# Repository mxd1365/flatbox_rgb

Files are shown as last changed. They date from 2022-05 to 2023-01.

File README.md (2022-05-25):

# Flatbox: Low profile hitbox-layout fightstick

This repository contains 3D-printable models, PCB design files and code needed to make an arcade controller that looks like this:

Assembled Flatbox

There are four major versions of the Flatbox. They all use Kailh low profile (choc v1) mechanical keyboard switches. The table below lists their main features. See the README for each version for details on how to make them.

version | [rev1.1](hardware-rev1.1) | [rev2](hardware-rev2) | [rev3](hardware-rev3) | [rev4](hardware-rev4) | [rev4_rgb](hardware-rev4_rgb)
------- | ------------------------- | --------------------- | --------------------- | --------------------- | ---------------------
case dimensions | 218x128x10mm | 218x130x10mm | 218x130x10mm | 218x130x10mm | 218x130x10mm
compatibility (using provided firmware) | PC, PS3 | PC, PS3 | PC, PS3, PS4 | PC, PS3 | PC, PS3
add-on board | Arduino Pro Micro | - | [Brook PS3/PS4](https://www.brookaccessory.com/detail/58690501/) | - | -
onboard chip | - | ATmega32U4 | - | RP2040 | RP2040
port | micro USB | USB-C | USB-C | USB-C | USB-C
SMT assembly required | no | yes | yes | yes | yes
firmware | [ATmega32U4](firmware-atmega32u4) | [ATmega32U4](firmware-atmega32u4) | [Brook](https://www.brookaccessory.com/download/PS3/) | [RP2040](firmware-rp2040) | [RP2040_RGB](firmware-rp2040_rgb)

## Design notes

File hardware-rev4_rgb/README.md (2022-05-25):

# Flatbox rev4

This is rev4 of the Flatbox with RBG added for each button. In this version the PCB includes a microcontroller and USB port. Everything is built in, you only have to add the switches (and flash the firmware).

To make one you will need:

* [3D printed case parts](3d-printed-case) - top and bottom
* [the PCB](pcb)
* 12x Kailh low profile (choc v1) switches of your choice
* (optionally) 12x Kailh low profile hotswap sockets
* [3D printed buttoncaps](../3d-printed-buttoncaps)
* 6x 6x6x5mm tact switches
* 7x 3x10mm wood screws
* some kind of rubber feet or non-slip padding for the bottom
* a soldering iron

I printed the case at 0.20mm layer height. The top part should be printed upside-down, the bottom part should be printed as-is. They don't require supports.

I used [JLCPCB](https://jlcpcb.com/) to make the PCB and assemble the SMD parts. The [included files](pcb) can be used with JLCPCB directly. If you want to use some other service, check the file formats that they expect. When ordering from JLCPCB, upload the Gerber zip, leave all the settings at default (you can choose the PCB color), then select "SMT Assembly" and upload the BOM and CPL files. PCB thickness should be 1.6mm.

The PCB you get from JLCPCB will look like this:

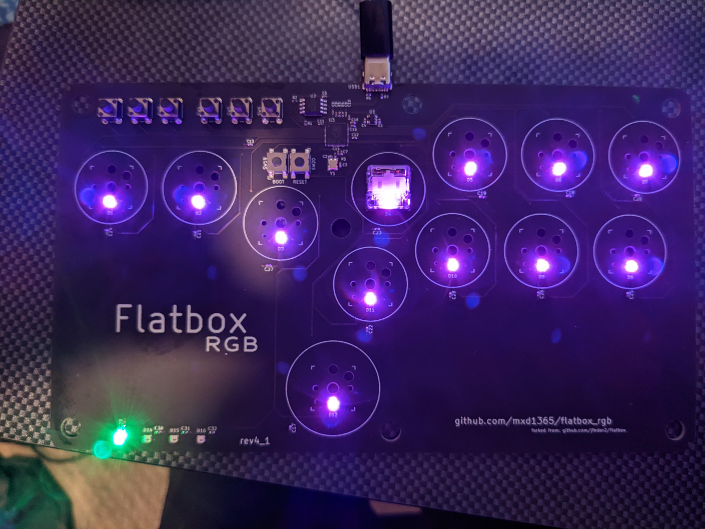
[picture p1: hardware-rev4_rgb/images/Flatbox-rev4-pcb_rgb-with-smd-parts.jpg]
Flatbox rev4 PCB with SMD parts assembled


For this version you must use hotswap sockets to connect the switches to the board

You don't have to use the [code](../firmware-rp2040) included here, you can use any other RP2040-compatible firmware. The included firmware works with the PS3 and PC.

To flash the firmware, connect the PCB to a computer with a USB cable, then press the RESET button while holding the BOOT button on the PCB. A drive named "RPI-RP2" should appear. Copy the [flatbox-rev4.uf2](firmware/flatbox-rev4.uf2) file to that drive. That's it.

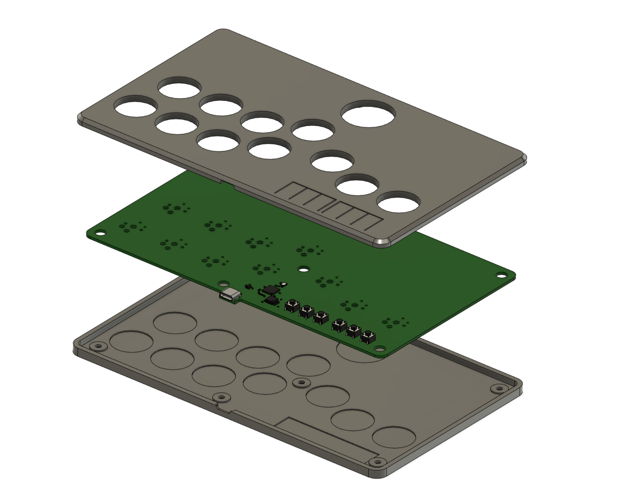
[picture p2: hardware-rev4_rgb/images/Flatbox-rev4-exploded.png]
Flatbox rev4 exploded view of the 3D printed case


PCB design licensed under [CC BY-SA 4.0](https://creativecommons.org/licenses/by-sa/4.0/).

PCB design uses the following libraries:

* [keyswitches.pretty](https://github.com/daprice/keyswitches.pretty) by [daprice](https://github.com/daprice) ([CC BY-SA 4.0](https://creativecommons.org/licenses/by-sa/4.0/))
* [Type-C.pretty](https://github.com/ai03-2725/Type-C.pretty) by [ai03-2725](https://github.com/ai03-2725)
* RP2040 library from the [minimal design example](https://datasheets.raspberrypi.org/rp2040/Minimal-KiCAD.zip) from the [Hardware design with RP2040](https://datasheets.raspberrypi.org/rp2040/hardware-design-with-rp2040.pdf) document

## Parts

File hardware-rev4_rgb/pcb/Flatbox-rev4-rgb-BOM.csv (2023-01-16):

Id | Designator | Package | Quantity | Designation | Supplier and ref
1 | SW8,SW9,SW18,SW10,SW11,SW12,SW13,SW14,SW15,SW16,SW17,SW7 | Kailh_socket_PG1350.kicad_mod | 12 | SW_Push
2 | SW4,SW2,SW5,SW1,SW3,SW6 | SW_PUSH_6mm_H5mm | 6 | SW_Push
3 | R7,R6 | R_0402_1005Metric | 2 | 5.1k
4 | USB1 | HRO-TYPE-C-31-M-12-Assembly | 1 | HRO-TYPE-C-31-M-12
5 | C1,C4,C8,C10 | C_0402_1005Metric | 4 | 1u
6 | C2,C3 | C_0402_1005Metric | 2 | 30p
7 | C5,C6,C7,C9,C15,C16,C13,C12,C14,C11 | C_0402_1005Metric | 10 | 100n
8 | R1,R5 | R_0402_1005Metric | 2 | 1k
9 | R2 | R_0402_1005Metric | 1 | 10k
10 | R4,R3 | R_0402_1005Metric | 2 | 27
11 | SW19,SW20 | SW_SPST_Omron_B3FS-100xP | 2 | SW_Push
12 | U1 | SOT-23-5 | 1 | TLV73333PDBV
13 | U2 | SOIC-8_5.23x5.23mm_P1.27mm | 1 | W25Q128JVS
14 | U3 | RP2040-QFN-56 | 1 | RP2040
15 | Y1 | Crystal_SMD_3225-4Pin_3.2x2.5mm | 1 | Crystal_GND24
16 | D10,D7,D12,D6,D15,D2,D5,D14,D8,D13,D4,D16,D11,D9,D3,D1 | LED_SK6812_EC20_1.5x1.5mm | 16 | SK6812-EC20
17 | C19,C31,C29,C30,C20,C26,C25,C18,C21,C32,C27,C23,C17,C24,C28,C22 | C_0402_1005Metric | 16 | 100nF
18 | H5,H7,H4,H2,H1,H6,H3 | MountingHole_6.4mm_M6 | 7 | MountingHole

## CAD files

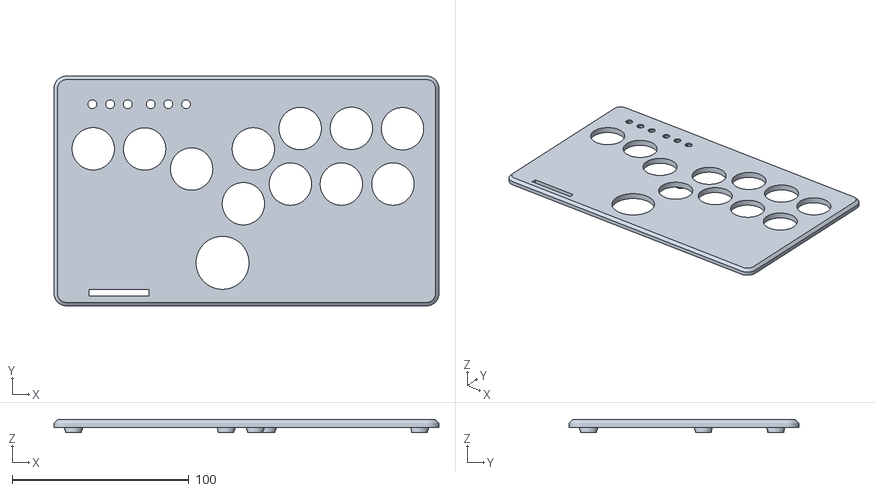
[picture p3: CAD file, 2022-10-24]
hardware-rev4_rgb/3d-printed-case/flatbox_rev4_rgb_top.stl
218.0 x 130.1 x 7.29

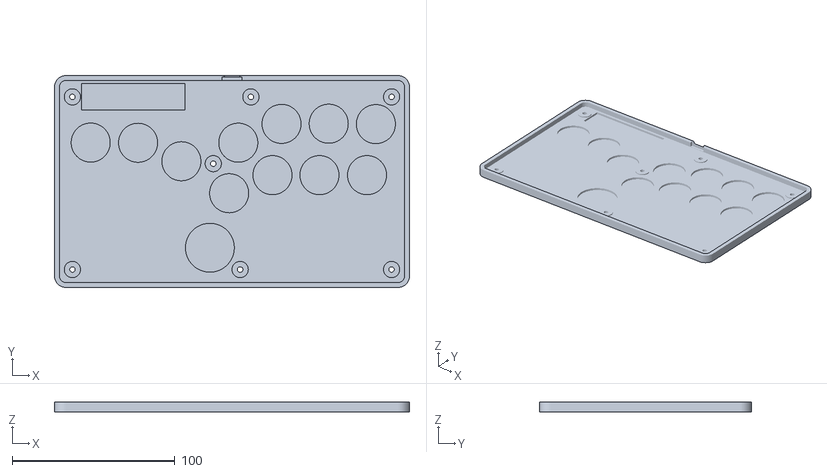
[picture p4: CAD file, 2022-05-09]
hardware-rev4_rgb/3d-printed-case/Flatbox-rev4-Bottom-hotswap.stl
218.0 x 130.1 x 6.20

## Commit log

2022-05-09 Initial commit. The lights work!
    [Flatbox-rev4-Bottom-hotswap.stl, Flatbox-rev4-case.step, Flatbox-rev4-rgb-BOM.csv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]
2022-06-27 Updated default ordering of button LEDs to be correct
2023-01-16 Updated With SK6812-EC20
    [Flatbox-rev4-rgb-BOM.csv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]
